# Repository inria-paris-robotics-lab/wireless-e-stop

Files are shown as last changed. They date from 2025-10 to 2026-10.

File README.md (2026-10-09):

# 🚨 Wireless E-Stop

A reliable **wireless emergency stop system** using nRF24L01+ modules and Arduino-compatible microcontrollers, developed by the *Inria Paris Robotics Lab*.
This system is designed for robots, machines, or any setup that needs a secure and fast wireless emergency stop.

## Project Overview

<table>
<tr>
<td>

This project implements a **wireless safety system** with the following key features:

- Secure wireless link using **nRF24L01+**
- Configurable RF channel to avoid interferences
- "Leaky bucket" timeout algorithm to detect signal loss
- Compact payload for fast transmission
</td>
<td align="right">
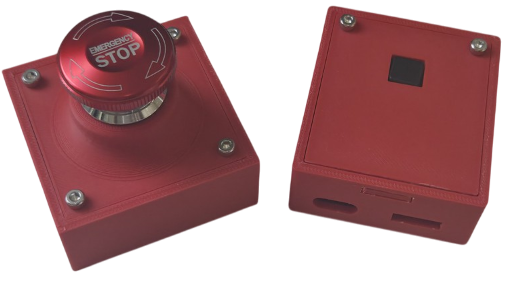
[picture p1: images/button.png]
Wireless E-Stop Render

</td>
</tr>
</table>

## Hardware Requirements

- 2x [Arduino-Nano NRF24L01+ microcontrollers](https://fr.aliexpress.com/item/1005006939062836.html)
- 1x [Relay module]( https://www.amazon.fr/gp/product/B08CDQ6CF8/ref=ox_sc_act_title_1?smid=A21312XZUBAZON&psc=1) (3.3V or 5V just make sure the relay voltage matches your microcontroller logic level)
- 1x [Emergency stop button](https://www.amazon.fr/gp/product/B08ZS8HZYV/ref=ox_sc_act_title_4?smid=A1DBC97EH2O973&th=1)
- 1x [Reset button](https://amazon.fr/dp/B0BF51N8CK) (for receiver)
- 1x [Signal LED (WSG2812B)](https://amazon.fr/dp/B0D5B7HDPP) (for receiver)
- 20x M3 screws
- 4x M1.6 screws
- 3D [printed cases](./hardware/CAD)

## Pin Connections

| **Arduino Pin**| **Transmitter** | **Receiver** |
|---|---|---|
| **3.3V** | —————————————— | Relay Module VCC |
| **5V** | —————————————— | Signal LED VCC |
| **GND** | GND, E-stop Button | GND, Relay Module, Signal LED, Reset Button|
| **D2** | E-stop Button (NC, internal pull-up)| Signal LED DIN (WS2812B) |
| **D3** | —————————————— | Reset Button (internal pull-up) |
| **D5** | —————————————— | Relay IN Pin |
| **D9** | used for nRF24L01 CSN | used for nRF24L01 CSN |
| **D10** | used for nRF24L01 CE | used for nRF24L01 CE |

## Software Overview

### Transmitter (`transmitter.ino`)

- Reads the state of the emergency stop button
- Sends a **boolean message** over RF every 100ms
- Allows RF channel configuration at boot by holding the button and using the Serial Monitor

### Receiver (`receiver.ino`)

- Listens for messages from the transmitter
- Uses a "leaky bucket" algorithm to detect communication loss
- Activates the **relay** (opens the circuit) if:
  - A message is received with `true`, or
  - No messages received for a set period
- Requires a **3-second button press** to rearm system

## RF Channel Configuration

Both transmitter and receiver support **on-boot channel setup**:

1. **Hold the button** during power-up (E-stop button for transmitter, Reset button for receiver)
2. Open the Serial Monitor at **115200 baud**
3. Enter a new channel (0–125)
4. Release the button to finish setup

> Tip: Use a **high channel number** (>100) to avoid interference with WiFi.

## Dependencies

Install via Arduino Library Manager:

- [`RF24`](https://github.com/nRF24/RF24) (transmitter and receiver)
- [`Adafruit NeoPixel`](https://github.com/adafruit/Adafruit_NeoPixel) (receiver only, for the signal LED)
- `EEPROM`, `SPI` and `avr/wdt` (built-in)

## Hardware Files

CAD and electronic schematics are located in the [`hardware/`](./hardware) folder.

Contents may include:

- Electronic schematics
- 3D printable case FreeCAD files and STL exports

## Additional tutorials for specific robots
Some robots like Unitree do not have external emergency connectors and require additional work to implement the e-stop. You can find tutorials for certains robots in the [robot-specific-tutorials](/robot-specific-tutorials/) folder.

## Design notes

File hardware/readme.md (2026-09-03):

# Hardware Components Reference

Below are screenshots of Amazon listings for each hardware component used in this project. This ensures reference information is retained even if product links change or are deleted.

## 1. Arduino Nano nRF24L01+

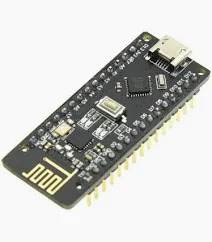
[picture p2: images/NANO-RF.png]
Amazon Screenshot - NANO-RF


## 2. Relay module

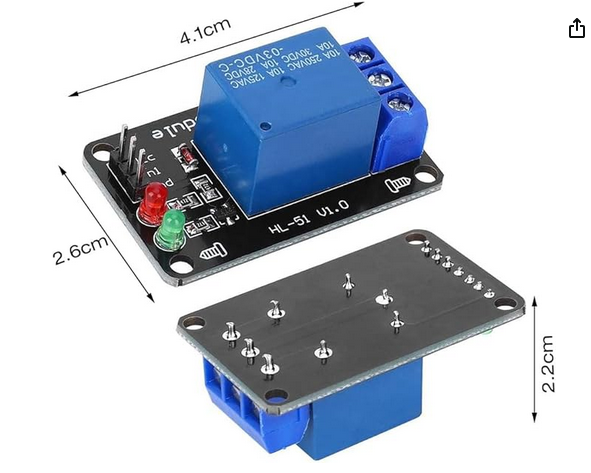
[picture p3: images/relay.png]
Amazon Screenshot - Relay module


## 3. Emergency stop button

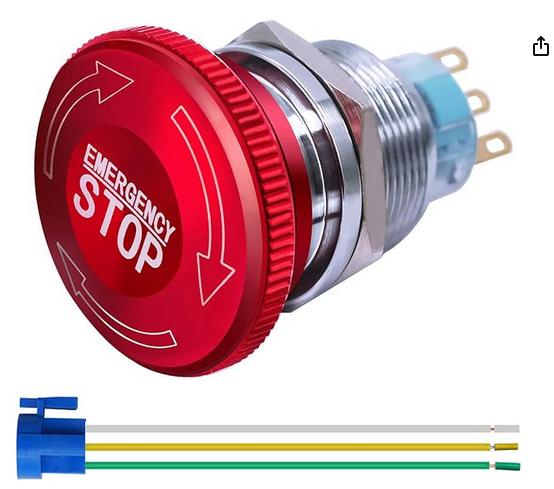
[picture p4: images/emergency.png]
Amazon Screenshot - Emergency stop button


## 4. Reset button
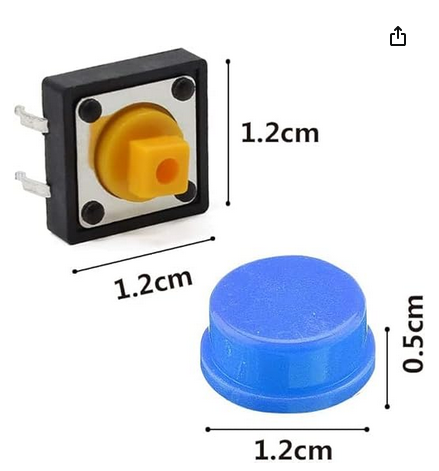
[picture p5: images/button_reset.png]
Amazon Screenshot - Reset button


## 5. LED WSG2812N
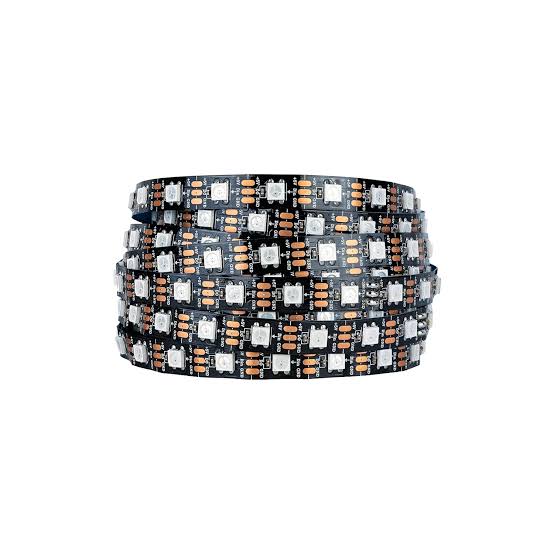
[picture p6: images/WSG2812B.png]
Amazon Screenshot - Led strip


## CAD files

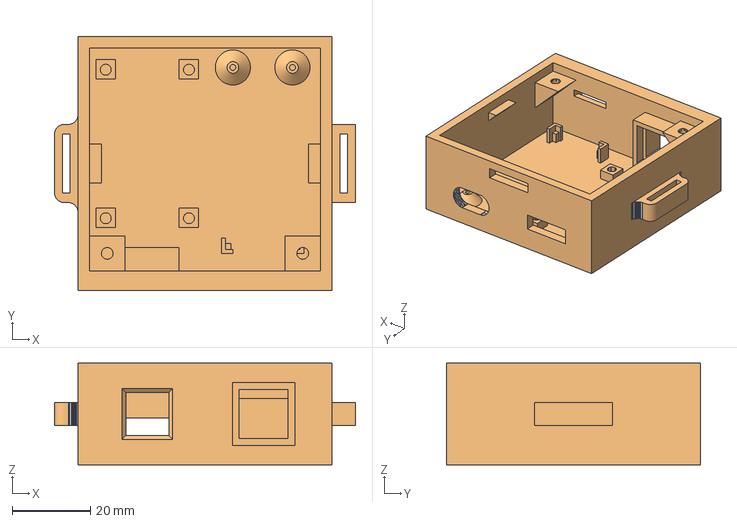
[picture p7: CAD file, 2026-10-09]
hardware/CAD/receiver_case.FCStd
77.0 x 65.0 x 26.0 mm
Corps
Corps (Meshed)

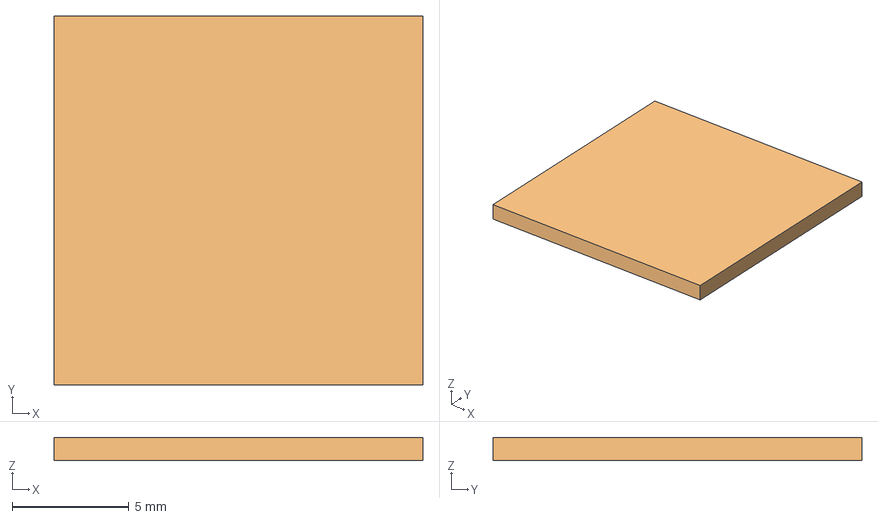
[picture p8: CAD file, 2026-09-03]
hardware/CAD/led_window.FCStd
15.8 x 15.8 x 1.00 mm
Corps
Corps (Meshed)

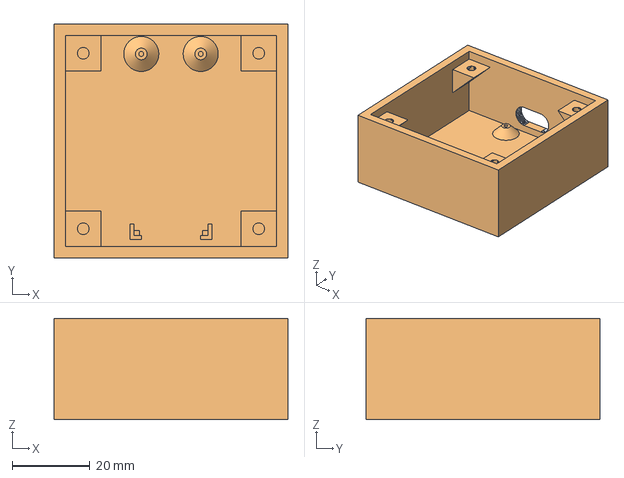
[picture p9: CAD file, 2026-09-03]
hardware/CAD/transmitter_case.FCStd
60.0 x 60.0 x 26.0 mm
Body (Meshed)

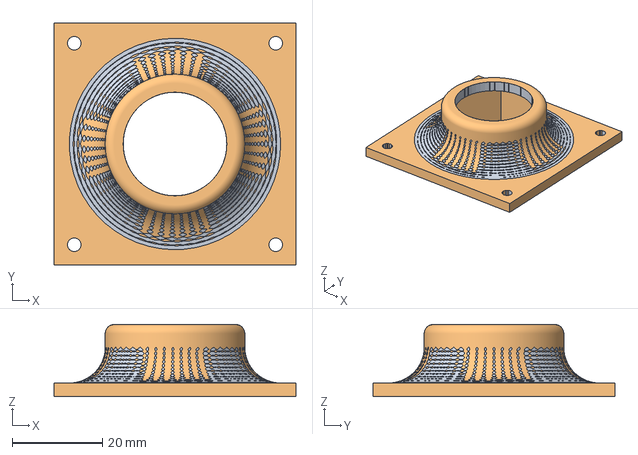
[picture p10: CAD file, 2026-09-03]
hardware/CAD/transmitter_top.FCStd
53.8 x 53.8 x 16.0 mm
Body (Meshed)

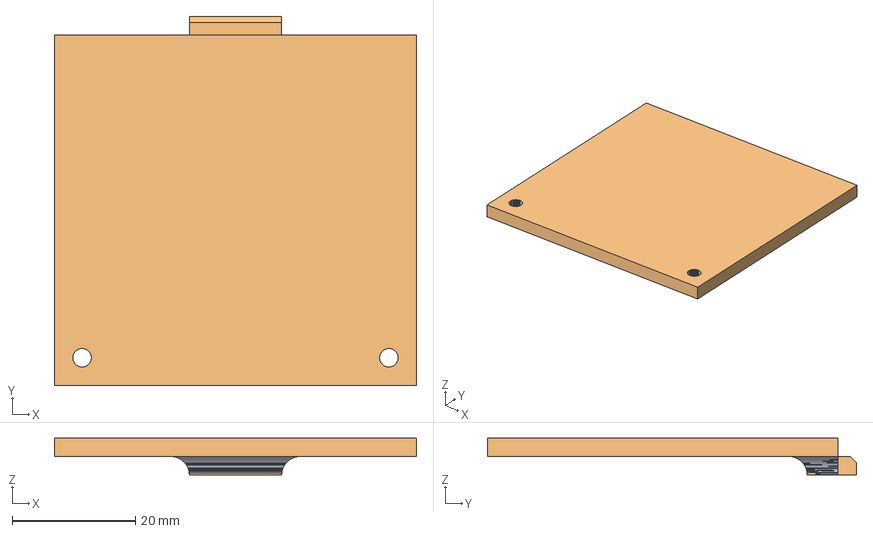
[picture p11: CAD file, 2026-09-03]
hardware/CAD/receiver_top.FCStd
58.8 x 59.9 x 6.00 mm
Body (Meshed)

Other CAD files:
hardware/CAD/led_window.stl
hardware/CAD/receiver_case.stl
hardware/CAD/receiver_top.stl
hardware/CAD/transmitter_case.stl
hardware/CAD/transmitter_top.stl

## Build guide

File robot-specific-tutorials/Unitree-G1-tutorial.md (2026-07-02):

Wiring tutorial on Unitree G1
===
> [!IMPORTANT]
> Remove the battery from the robot before opening it.

Lay the robot on its front so that you can access the screws in the back.   
Unscrew the two screws of the handle.   

<div align="center">
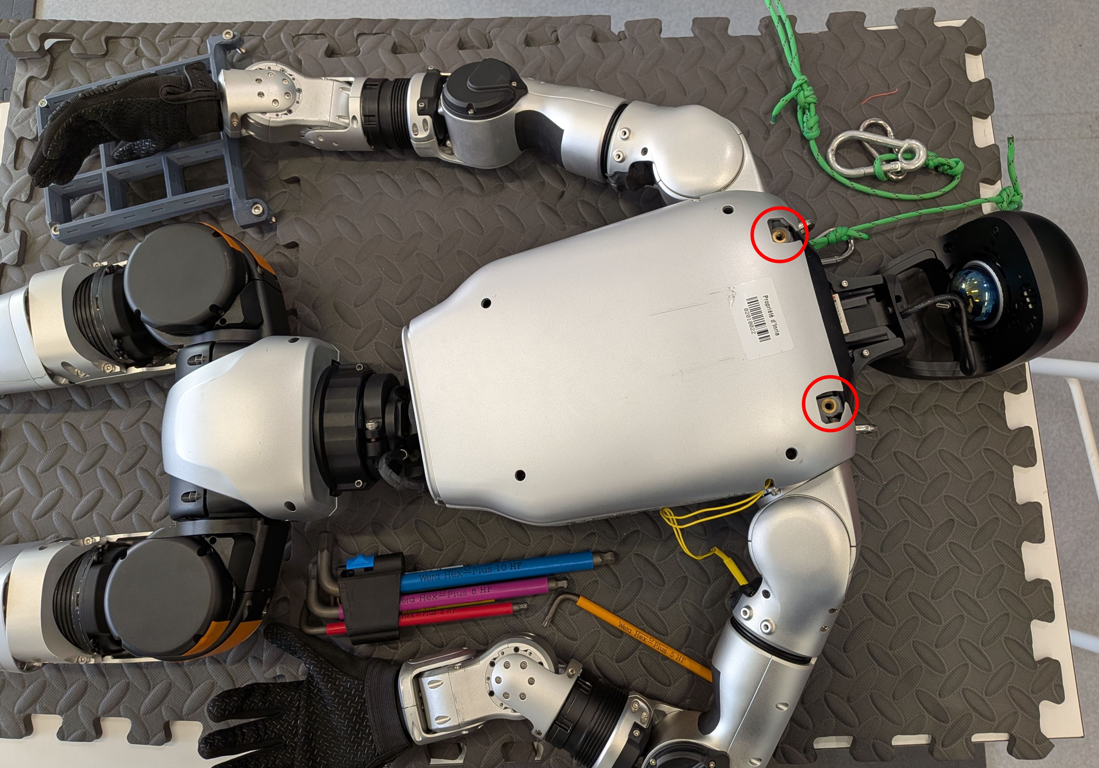
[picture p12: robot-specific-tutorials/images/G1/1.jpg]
Robot on its back with the 2 screws to remove marked in red

</div>
<br>

With a plastic card pop open the plastic outer shell. The clips that needs to be pushed are marked in red in the following pictures, be careful to also remove the one on top of the shoulder.   

<table>
    <td>
        <div align="center">
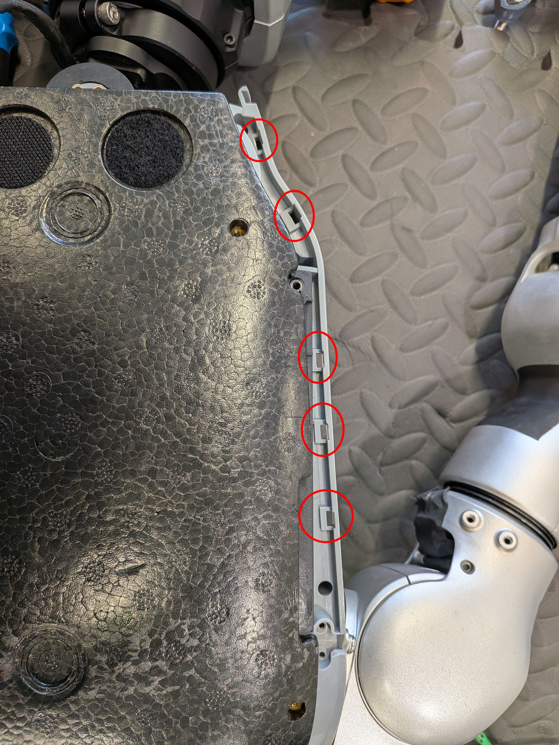
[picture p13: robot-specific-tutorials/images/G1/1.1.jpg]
            
        </div>
    </td>
        <td>
        <div align="center">
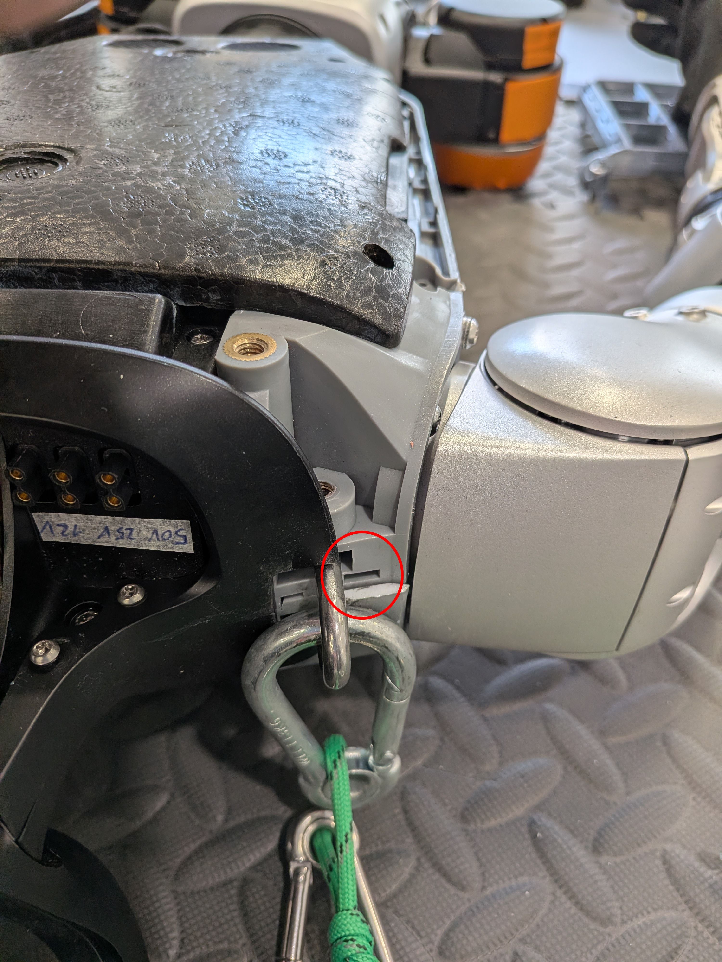
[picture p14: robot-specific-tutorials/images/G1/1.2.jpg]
            
        </div>
    </td>
</table>
<br>

Next to remove the polyester pannel unscrew the 4 screws marked in red and carefully pull. The bottom part of the pannel (where there are two velcro pads) is double taped, use a plastic card to carefuly unstick it and pull off the pannel entirely.  

<div align="center">
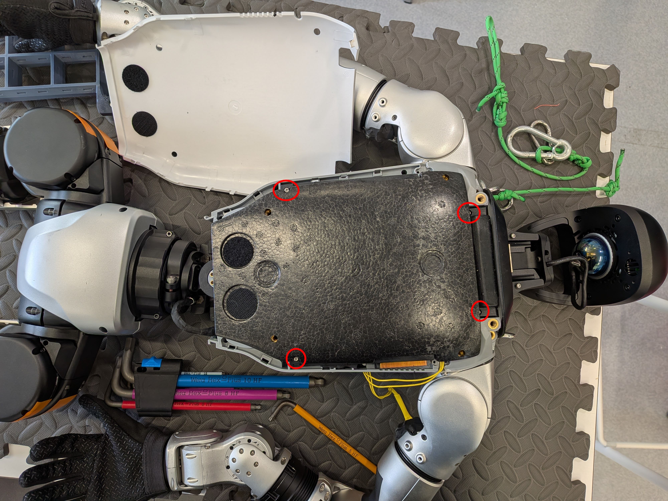
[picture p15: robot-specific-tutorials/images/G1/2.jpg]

</div>
<br>

The emergency stop plug is dead-center (in red).   
<div align="center">
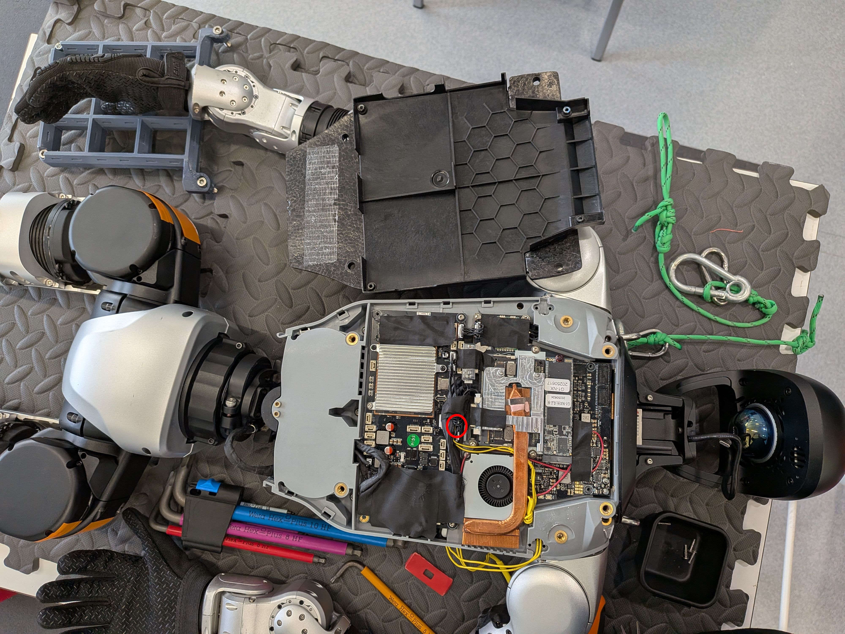
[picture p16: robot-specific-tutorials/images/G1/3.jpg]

</div>
<br>

You will need to wire 2 wires to a GH 1.25 mm 2 pin male connector.  Keep the other end of the wires unsoldered so that you can thread them under the caloduc and through the vent to the outside the robot.
<table>
    <td>
        <div align="center">
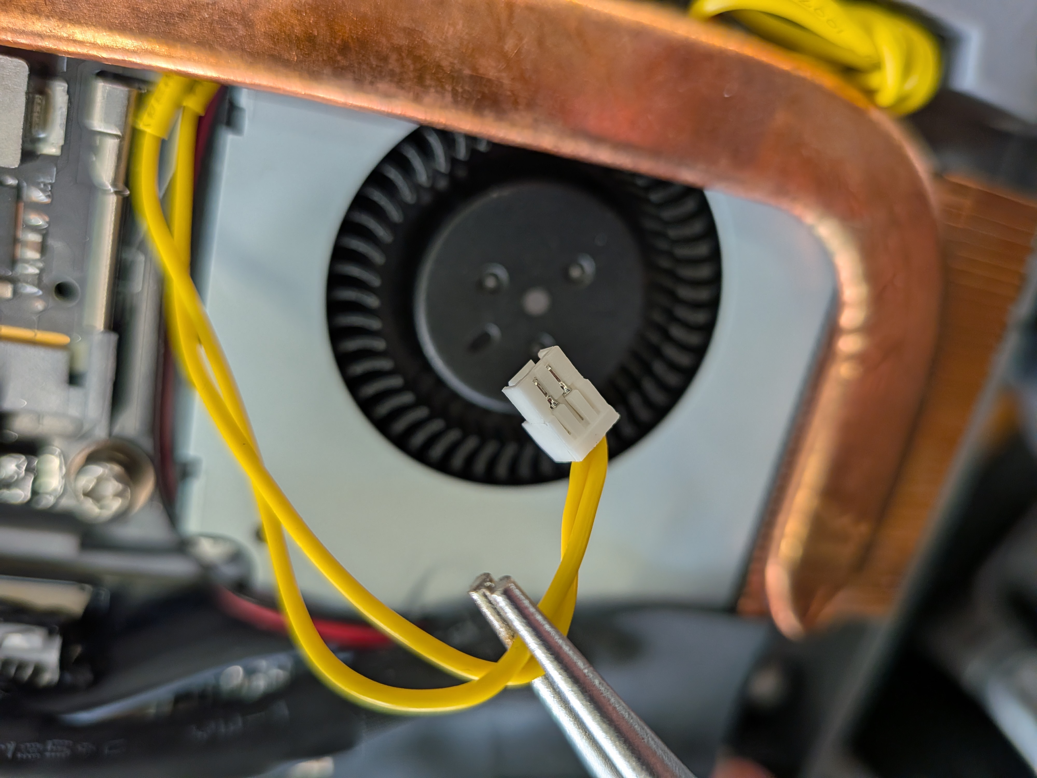
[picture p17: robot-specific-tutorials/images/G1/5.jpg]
            
        </div>
    </td>
        <td>
        <div align="center">
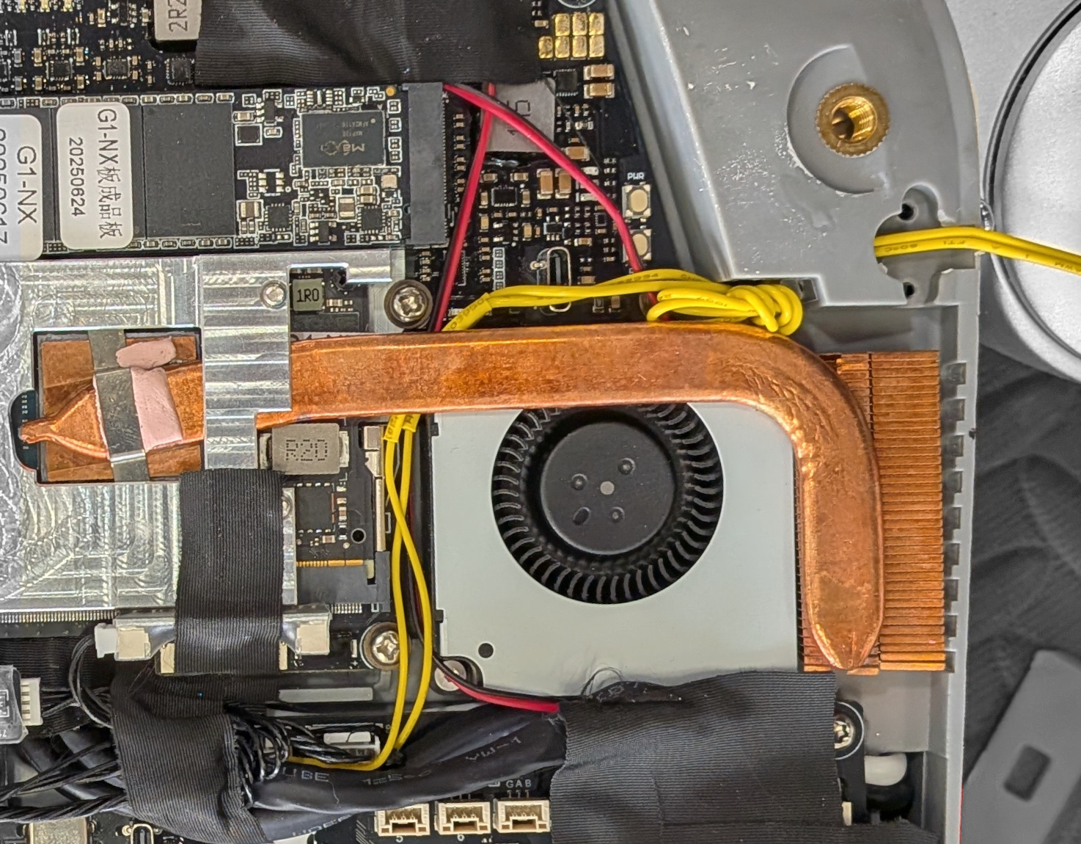
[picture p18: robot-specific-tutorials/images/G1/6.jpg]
            
        </div>
    </td>
</table>
<br>

You can connect the other end of the wire (the part that will be outside of the robot) directly to the receiver module or to any connector of your liking.  
We use a female 5.5 x 2.1mm Power Jack connector plugged to a male connector of the same type soldered to the receiver :
<div align="center">
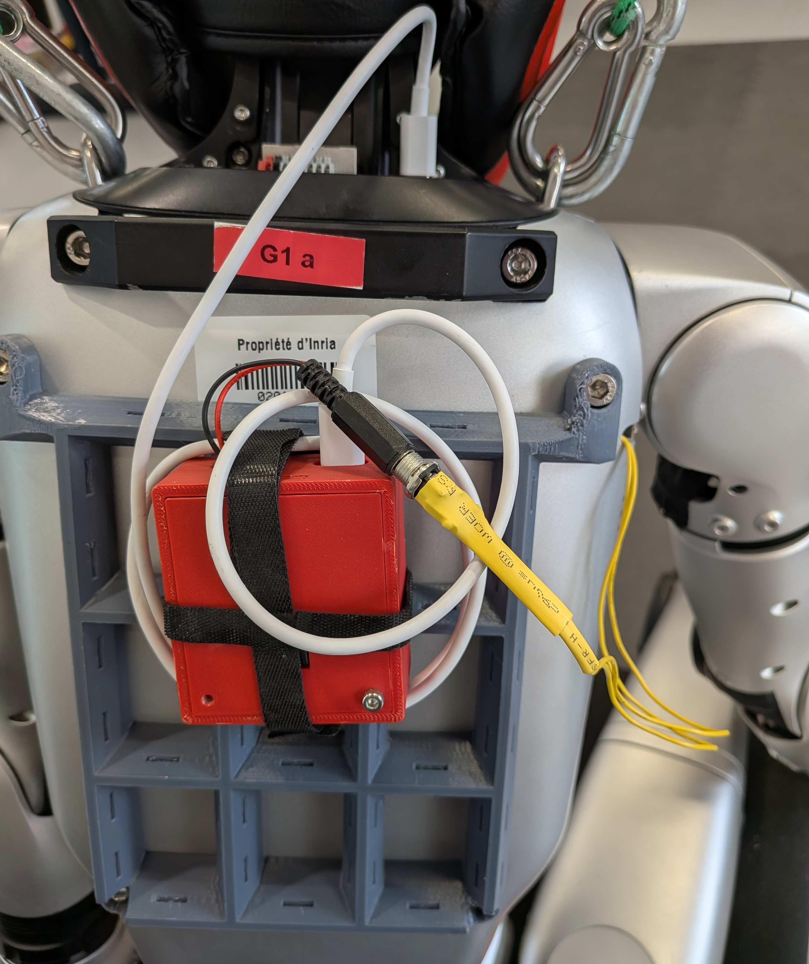
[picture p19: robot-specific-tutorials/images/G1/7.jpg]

</div>
<br>   

The "backpack" can be found in our [CAD-parts repository](https://github.com/inria-paris-robotics-lab/CAD-parts/).

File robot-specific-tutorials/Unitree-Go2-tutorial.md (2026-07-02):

Wiring tutorial on Unitree Go2
===
> [!IMPORTANT]
> Remove the battery from the robot before opening it.

Unscrew the two screws of the handle.   

<div align="center">
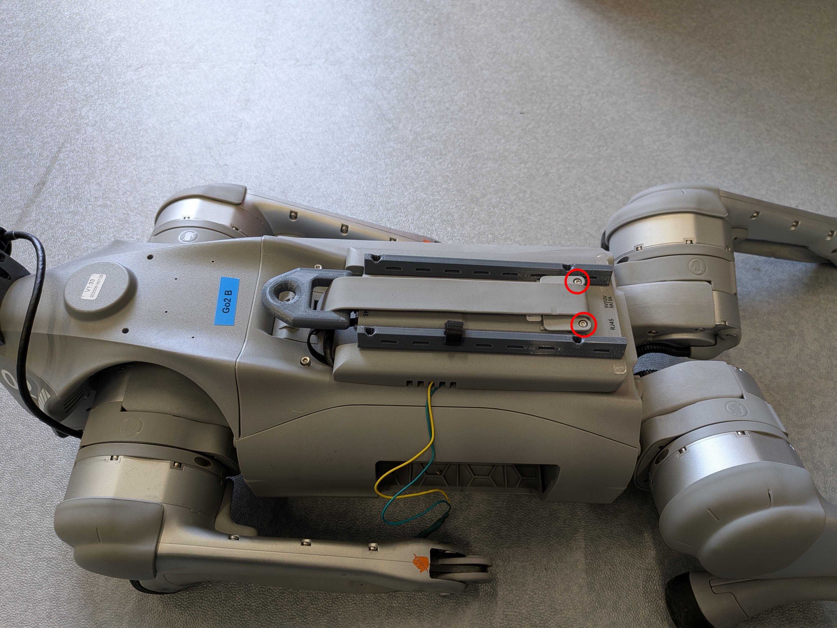
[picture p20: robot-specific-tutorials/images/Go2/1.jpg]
The 2 screws of the handle marked in red

</div>
<br>

Remove the 4 screws that holds the Jetson.

<div align="center">
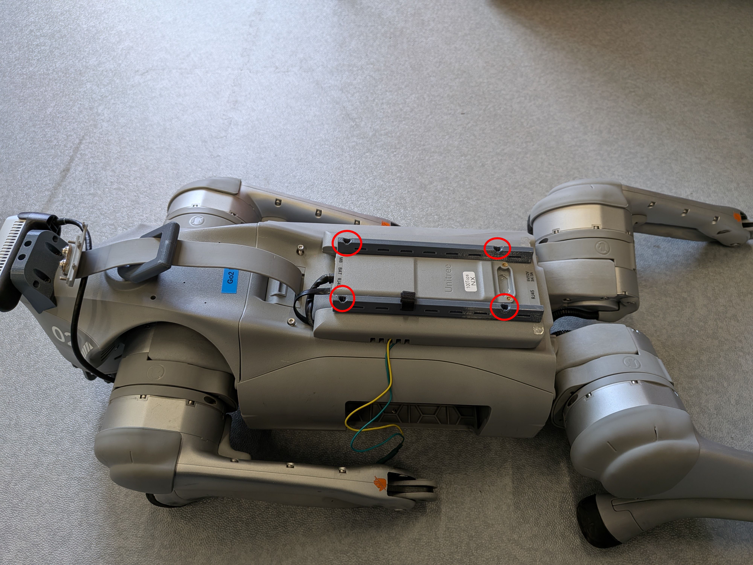
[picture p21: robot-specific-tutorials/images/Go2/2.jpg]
The 4 screws of the jetson marked in red

</div>
<br>

Next, unplug the power and ethernet wire connecting the robot to the Jetson and put the Jetson aside.   
<div align="center">
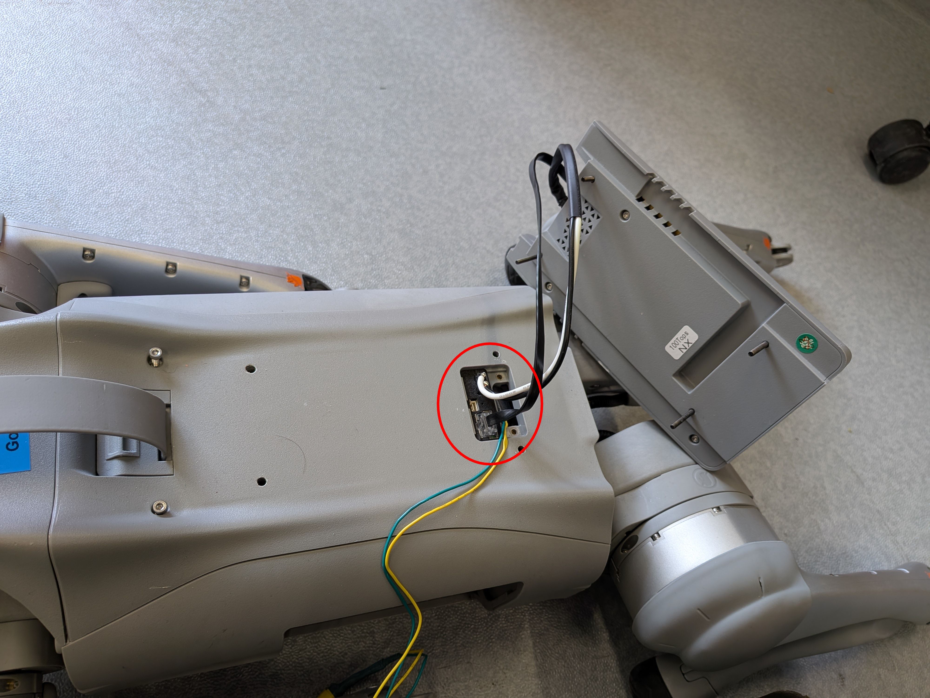
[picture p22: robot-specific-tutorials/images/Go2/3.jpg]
The wires to unplug marked in red

</div>
<br>

To remove the top plastic shell of the robot and access the mother board, remove 4 screws: two on the top and two on the back, near the legs actuators.    
<table>
    <td>
        <div align="center">
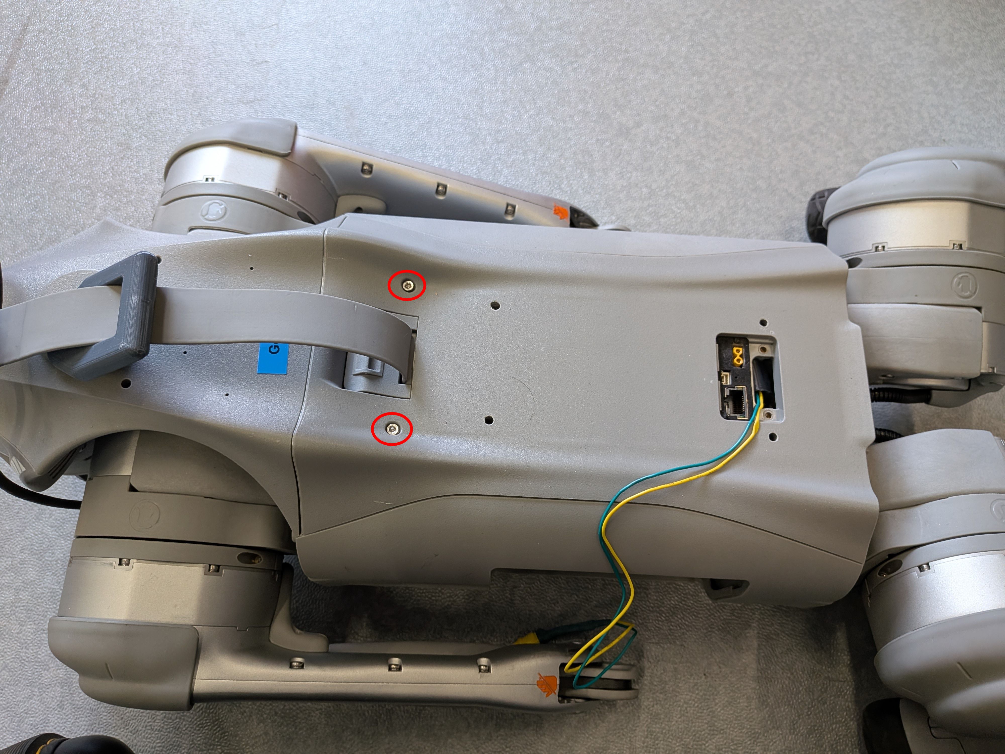
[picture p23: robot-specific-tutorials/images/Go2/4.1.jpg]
Localisation of the top screws
            
        </div>
    </td>
        <td>
        <div align="center">
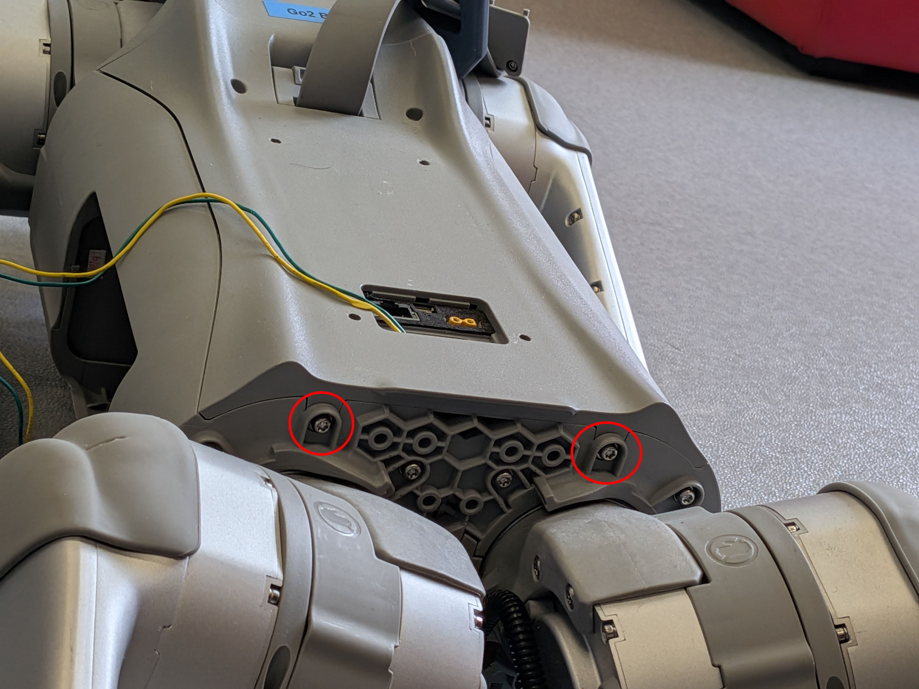
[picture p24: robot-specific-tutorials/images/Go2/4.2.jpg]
Localisation of the back screws
            
        </div>
    </td>
</table>
<br>

Remove the cover.

<div align="center">
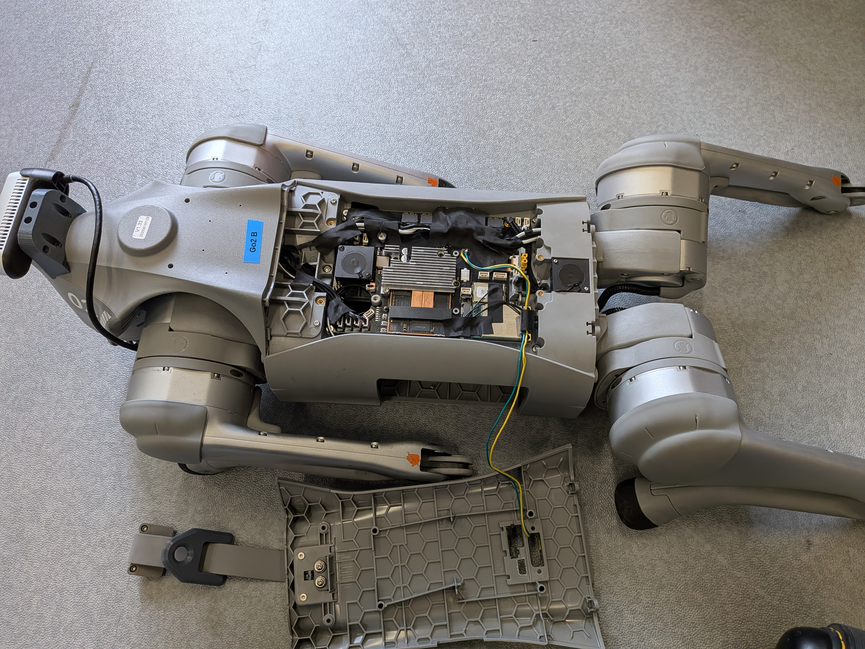
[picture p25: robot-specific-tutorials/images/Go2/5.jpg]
The robot with the cover opened

</div>
<br>

Solder two wires directly to the mother board on the emegency pads (in red). And thread them through the hole in the top pannel that is used for the ethernet and the power for the Jetson.   

<div align="center">
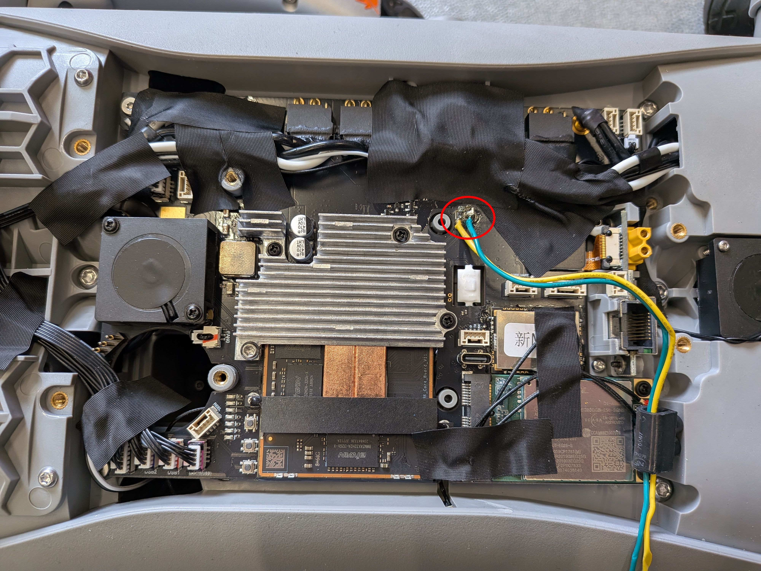
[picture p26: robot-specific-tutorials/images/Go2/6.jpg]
The robot motherboard

</div>
<br>

You can connect the other end of the wire (the part that will be outside of the robot) directly to the receiver module or to any connector of your liking.  
We use a female 5.5 x 2.1mm Power Jack connector plugged to a male connector of the same type soldered to the receiver.

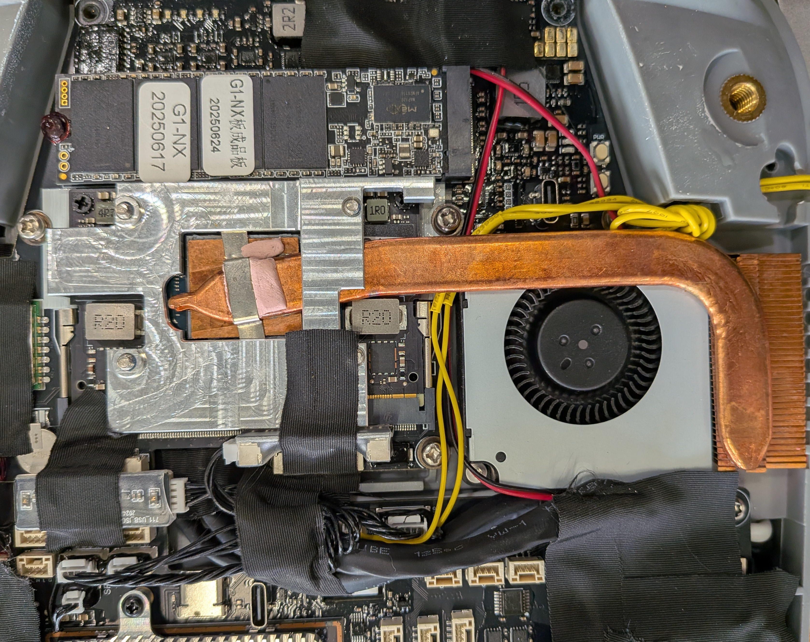
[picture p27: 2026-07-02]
robot-specific-tutorials/images/G1/4.jpg

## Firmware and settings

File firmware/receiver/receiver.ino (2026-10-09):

#include <Adafruit_NeoPixel.h>
#include <EEPROM.h>
#include <RF24.h>
#include <SPI.h>
#include <avr/wdt.h>
#include <nRF24L01.h>

#define CE_PIN 10
#define CSN_PIN 9
#define RESET_BUTTON_PIN 3
#define RELAY_PIN 5
#define LED_PIN 2
#define LED_COUNT 1

// IMPORTANT : This relay logic is made for robot on COM + NC
// RELAY_RUN  = Open COM-NC  -> normal state
// RELAY_STOP = Close COM-NC  -> trigger emergency stop on the robot

#define RELAY_RUN LOW
#define RELAY_STOP HIGH

int EEPROM_ADDRESS = 0; // Address to store the channel
int ChannelNumber = 0;  // Variable to hold the channel number

RF24 radio(CE_PIN, CSN_PIN);

const byte address[6] = "1234"; // Address for communication

int state = 0; // Internal state 0: armed, 1: secured

int relay_state = RELAY_STOP;

bool msg = false; // Alarm message

bool radioOK = false;

const unsigned long RADIO_INIT_TIMEOUT = 5000;

// Reset button parameters
const unsigned long DEBOUNCE_DELAY = 30;
unsigned long lastButtonChange = 0;
bool lastRawButtonState = HIGH;
bool buttonState = HIGH;

bool buttonPressed = false;
unsigned long buttonPressTime = 0;
const unsigned long RESET_HOLD_TIME = 3000; // Time in ms to hold button to reset

// Leaky bucket parameters
const int BUCKET_CAPACITY = 8;     // Bucket capacity before triggering alarm
int bucketLevel = BUCKET_CAPACITY; // Current bucket level (starts full)
unsigned long lastLeakTime = 0;    // Last time the bucket leaked
const long LEAK_INTERVAL = 150;    // Bucket loses 1 point every leak interval (ms)

// Heartbeat LED
unsigned long lastHeartbeat = 0;
bool heartbeatOn = false;
const unsigned long HEARTBEAT_INTERVAL = 500;

// Signal LED
Adafruit_NeoPixel led(LED_COUNT, LED_PIN, NEO_GRB + NEO_KHZ800);
void setLed(uint8_t r, uint8_t g, uint8_t b) {
  led.setPixelColor(0, led.Color(r, g, b));
  led.show();
}

bool readButtonDebounced() {
  bool raw = digitalRead(RESET_BUTTON_PIN);
  if (raw != lastRawButtonState) {
    lastButtonChange = millis();
    lastRawButtonState = raw;
  }
  if (millis() - lastButtonChange > DEBOUNCE_DELAY) {
    buttonState = raw;
  }
  return buttonState;
}

void setRelayRun() {
  relay_state = RELAY_RUN;
  digitalWrite(RELAY_PIN, relay_state);
  heartbeatOn = true;
  lastHeartbeat = millis();
  setLed(0, 0, 255);
}

void setRelayStop() {
  relay_state = RELAY_STOP;
  digitalWrite(RELAY_PIN, relay_state);
  setLed(255, 0, 0);
}

void setup() {
  wdt_disable();

  pinMode(RELAY_PIN, OUTPUT);
  pinMode(RESET_BUTTON_PIN, INPUT_PULLUP);

  // setup led
  led.begin();
  led.setBrightness(50);

  setRelayStop();

  EEPROM.get(EEPROM_ADDRESS, ChannelNumber);
  if (ChannelNumber < 0 || ChannelNumber > 125) { // Validate channel
    ChannelNumber = 110;                          // Default channel
    EEPROM.put(EEPROM_ADDRESS, ChannelNumber);
  }

  // Check Startup mode
  if (digitalRead(RESET_BUTTON_PIN) == LOW) {
    // Set relay stop to avoid robto working during setup
    setRelayStop();
    Serial.begin(115200);
    setLed(255, 255, 0);

    Serial.println("Mode Setup");
    Serial.print("Current Channel set to: ");
    Serial.println(ChannelNumber);
    Serial.println("Please enter the new Channel (0-125, you should use high values to avoid WiFi "
                   "interference): ");
    while (!Serial.available()) {
      // wait for user input
    }
    int newChannel = Serial.parseInt();
    while (!(newChannel >= 0 && newChannel <= 125)) {
      Serial.println("Invalid input. Please enter a valid channel (0-125): ");
      while (!Serial.available()) {
      }
      newChannel = Serial.parseInt();
    }
    if (newChannel != ChannelNumber) {
      Serial.print("Default Channel set to: ");
      Serial.println(newChannel);
      EEPROM.put(EEPROM_ADDRESS, newChannel);
      ChannelNumber = newChannel;
    }
    Serial.println("Setup channel done.");
    while (digitalRead(RESET_BUTTON_PIN) == LOW) {
      delay(100);
    }
    Serial.end();
  }

  // Initialize nRF24L01
  unsigned long radioInitStart = millis();
  bool blink = false;
  while (!radioOK && (millis() - radioInitStart < RADIO_INIT_TIMEOUT)) {
    radioOK = radio.begin();
    if (!radioOK) {
      if (blink)
        setLed(255, 150, 0);
      else
        setLed(0, 0, 0);
      blink = !blink;
      delay(200);
    }
  }

  if (radioOK) {
    radio.setPALevel(RF24_PA_MAX);     // Set the maximum propagation distance
    radio.setPayloadSize(sizeof(msg)); // Set the payload size (help to speed up communication)
    radio.setChannel(ChannelNumber);   // Set the channel from storage
    radio.setDataRate(RF24_1MBPS);     // Set data rate
    radio.openReadingPipe(1, address); // Set the address for communication
    radio.startListening();            // Set the module as receiver
    state = 0;
    setRelayRun();
  } else {
    state = 1;
    setRelayStop();
  }

  lastLeakTime = millis();

  wdt_enable(WDTO_1S);
}

void loop() {
  wdt_reset();

  uint8_t pipe;

  if (!radioOK) {
    return;
  }

  if (state == 0 && millis() - lastHeartbeat > HEARTBEAT_INTERVAL) {
    lastHeartbeat = millis();
    heartbeatOn = !heartbeatOn;
    setLed(0, 0, heartbeatOn ? 255 : 60);
  }

  // Handle reset button when system is secured
  if (state == 1) {
    if (readButtonDebounced() == LOW) {
      if (!buttonPressed) {
        buttonPressed = true;
        buttonPressTime = millis();
      } else {
        if (millis() - buttonPressTime >= RESET_HOLD_TIME) { // If button held long enough
          // Reset the system (radioOK deja garanti true a ce point)
          state = 0; // Change state to armed
          setRelayRun();
          bucketLevel = BUCKET_CAPACITY; // Reset bucket level
          lastLeakTime = millis();       // Reset leak timer
          msg = false;
          buttonPressed = false;
        }
      }
    } else {
      buttonPressed = false;
    }
  }

  // Check for incoming radio data and take the most recent message
  while (radio.available(&pipe)) {
    radio.read(&msg, sizeof(msg));
    bucketLevel = min(bucketLevel + 1, BUCKET_CAPACITY);
    lastLeakTime = millis();
  }

  if (msg && state == 0) { // If system is armed and alarm signal received
    state = 1;             // Change state to secured
    setRelayStop();
  } else {
    if (state == 0) {
      // No data received
      if (millis() - lastLeakTime > LEAK_INTERVAL) {
        bucketLevel = max(bucketLevel - 1, 0); // Decrease bucket level
        lastLeakTime = millis();               // Update last leak time
      }
      // Check if bucket level is empty
      if (bucketLevel == 0 && state == 0) {
        state = 1;
        setRelayStop();
      }
    }
  }
}

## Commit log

2026-03-09 update cad
    [receiver_case.FCStd, receiver_top.FCStd, receiver_top.stl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]
2026-03-10 update receiver case
    [receiver_case.FCStd, receiver_top.FCStd, receiver_top.stl]
2026-06-17 move button and signal LED
    [receiver_top.FCStd, receiver_top.stl]
2026-07-02 Wiring tutorial for the G1
2026-07-20 New receiver design
    [receiver.kicad_pcb, receiver.kicad_sch, receiver_case.FCStd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]
2026-07-23 stl update
    [transmitter_case.stl, transmitter_top.FCStd]
2026-07-23 update pin and setup logic
    [led_window.stl]
2026-07-23 led window
    [led_window.FCStd]
2026-10-06 fix relay fixation into receiver
    [receiver_case.FCStd, receiver_case.stl]
